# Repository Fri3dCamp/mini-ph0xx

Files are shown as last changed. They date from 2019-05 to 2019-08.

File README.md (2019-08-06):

# mini-ph0xx

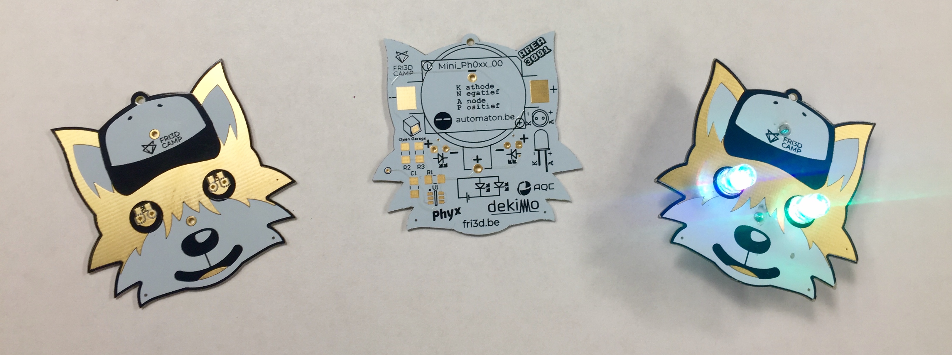
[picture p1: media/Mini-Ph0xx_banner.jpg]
Mini-Ph0xx banner


Design files voor de kleine badge die we op de [Maker Faire Gent 2019](http://makerfairegent.be) gebruikten om 1000 mensen te leren solderen.

De badge werd ontworpen door Wim Van Gool en Toon Vandeputte. Toon werkte een ontwerp uit in Illustrator en Wim integreerde dat met de PCB layout in Altium. Deze mini ph0xx badge is in alle opzichten de kleine broer van de [ph0xx badge](https://github.com/Fri3dCamp/badge) van Fri3d Camp 2018.

De badge heeft een through-hole design en twee SMD designs op 1 printplaat. Allen doen ze met een celbatterij twee oogjes oplichten. Met het tweede SMD circuit kan je het kopervlak rond de oortjes gebruiken als aan/uit touchpad.

Deze repository bevat 
* [De design files voor Altium](design)
* [De productiefiles van de rev.00 PCB zoals gebruikt op de Maker Faire](output/Mini-Ph0xx_00/PCB%20Production)
* [De productiefiles van de rev.01 PCB](output/Mini-Ph0xx_01/PCB%20Production)
* [Bill of Materials van de 3 circuits](output/Mini-Ph0xx_00/BOM)
* [Bill of Materials van de basic versie](output/Mini-Ph0xx_01/BOM)
* [Design in PDF formaat van rev.00](output/Mini-Ph0xx_00/Mini-Ph0xx_00.PDF)
* [Design in PDF formaat van rev.01](output/Mini-Ph0xx_01/Mini-Ph0xx_01.PDF)
* [Handleiding](Handleiding/Mini%20Ph0xx%20handleiding.pdf)
* [Iedereen kan solderen roll-up poster](Handleiding/Iedereen%20kan%20solderen.pdf)

Gebruik, copieer, verspreid!

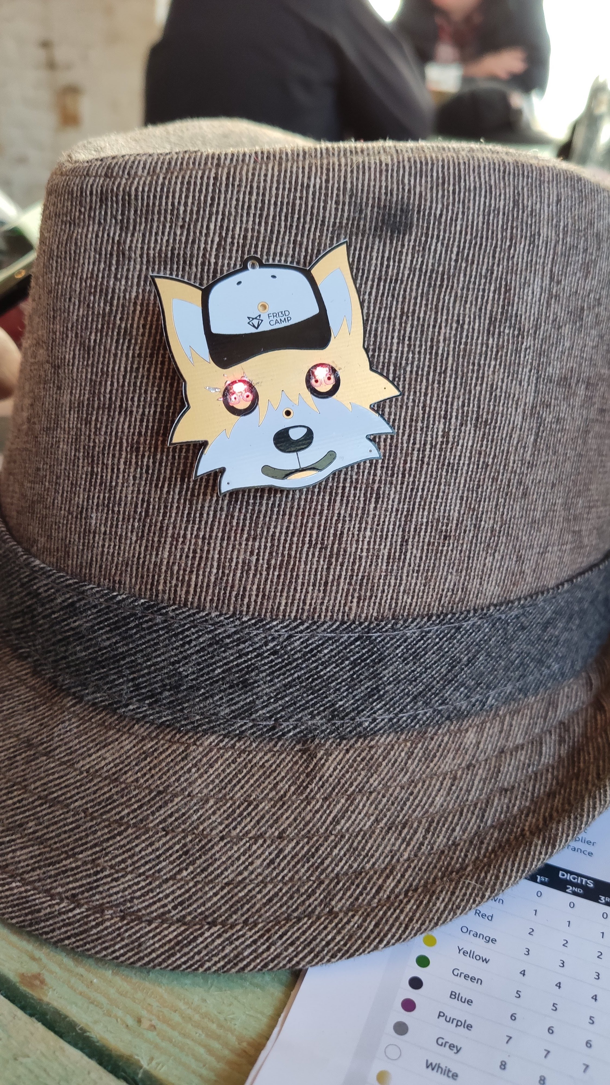
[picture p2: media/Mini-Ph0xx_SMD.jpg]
Mini-Ph0xx SMD


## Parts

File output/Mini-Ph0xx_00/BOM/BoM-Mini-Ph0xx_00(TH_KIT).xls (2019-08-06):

Bill of Materials |  |  | Mini Ph0xx
Project: |  | Mini-Ph0xx_00.PrjPcb
Revision: |  | 00
Variant: |  | TH_KIT
Creation Date: | 06/05/2019 | 22:11:42
Print Date: | 2019-05-06 | 22:12:12
Footprint | Comment | LibRef | Designator | Value | Description | Supplier 1 | Supplier Part Number 1 | Quantity
BAT_CR2032 | CR2032 Battery Holder | BAT 20mm Coin Cell Holder Generic | BAT1 | CR2032 |  | China |  | 1
LED_5MM_BL | Default 5mm Blue LED | LED Blue 5mm | D1, D2 |  |  |  |  | 2
 |  |  |  |  |  |  |  | 3
Approved |  | Notes

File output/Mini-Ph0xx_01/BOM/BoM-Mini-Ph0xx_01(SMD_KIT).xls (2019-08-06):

Bill of Materials |  |  | Mini Ph0xx
Project: |  | Fri3D_2019_SolderBadge_01.PrjPcb
Revision: |  | 01
Variant: |  | SMD_KIT
Creation Date: | 06/08/2019 | 21:38:42
Print Date: | 2019-08-06 | 21:40:05
Footprint | Comment | LibRef | Designator | Value | Description | Supplier 1 | Supplier Part Number 1 | Quantity
BAT_CR2032_KEY_1060 | CR2032 SMD Battery Holder | BAT # 20mm Coin Cell Holder Keystone 1060 | BAT2 | CR2032 |  | Digi-key | 36-1060-ND | 1
LED_0805_BL | Default 0805 Blue LED | LED # Blue 0805 | D3, D4 |  |  | Farnell | 2217980 | 2
 |  |  |  |  |  |  |  | 3
Approved |  | Notes

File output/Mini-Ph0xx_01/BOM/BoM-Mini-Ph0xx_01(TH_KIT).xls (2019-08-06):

Bill of Materials |  |  | Mini Ph0xx
Project: |  | Fri3D_2019_SolderBadge_01.PrjPcb
Revision: |  | 01
Variant: |  | TH_KIT
Creation Date: | 06/08/2019 | 21:38:14
Print Date: | 2019-08-06 | 21:39:32
Footprint | Comment | LibRef | Designator | Value | Description | Supplier 1 | Supplier Part Number 1 | Quantity
BAT_CR2032_China | CR2032 Battery Holder | BAT 20mm Coin Cell Holder Generic | BAT1 | CR2032 |  | China |  | 1
LED_5MM_BL | Default 5mm Blue LED | LED Blue 5mm | D1, D2 |  |  |  |  | 2
 |  |  |  |  |  |  |  | 3
Approved |  | Notes

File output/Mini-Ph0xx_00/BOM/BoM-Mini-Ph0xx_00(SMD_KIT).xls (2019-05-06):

Bill of Materials |  |  | Mini Ph0xx
Project: |  | Mini-Ph0xx_00.PrjPcb
Revision: |  | 00
Variant: |  | SMD_KIT
Creation Date: | 06/05/2019 | 22:11:46
Print Date: | 2019-05-06 | 22:12:49
Footprint | Comment | LibRef | Designator | Value | Description | Supplier 1 | Supplier Part Number 1 | Quantity
BAT_CR2032_KEY_1060 | CR2032 SMD Battery Holder | BAT # 20mm Coin Cell Holder Keystone 1060 | BAT2 | CR2032 |  | Digi-key | 36-1060-ND | 1
LED_0805_RD | Default 0805 Red LED | LED # Red 0805 | D3, D4 |  |  | Farnell | 2099236 | 2
R1206 | RESISTOR | RES # 0R 1206 | R1 | 0R |  | Farnell | 2497983 | 1
R1206 | RESISTOR | RES # 33R 1206 | R2, R3 | 33R |  |  |  | 2
 |  |  |  |  |  |  |  | 6
Approved |  | Notes

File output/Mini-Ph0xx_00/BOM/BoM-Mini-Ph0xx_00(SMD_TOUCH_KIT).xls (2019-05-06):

Bill of Materials |  |  | Mini Ph0xx
Project: |  | Mini-Ph0xx_00.PrjPcb
Revision: |  | 00
Variant: |  | SMD_TOUCH_KIT
Creation Date: | 06/05/2019 | 22:11:51
Print Date: | 2019-05-06 | 22:12:28
Footprint | Comment | LibRef | Designator | Value | Description | Supplier 1 | Supplier Part Number 1 | Quantity
BAT_CR2032_KEY_1060 | CR2032 SMD Battery Holder | BAT # 20mm Coin Cell Holder Keystone 1060 | BAT2 | CR2032 |  | Digi-key | 36-1060-ND | 1
C1206_N | CAP_CERAMIC | CAP # 22pF 50V 1206 | C1 | 22pF 50V | Capacitor Ceramic |  |  | 1
LED_0805_RD | Default 0805 Red LED | LED # Red 0805 | D3, D4 |  |  | Farnell | 2099236 | 2
R1206 | RESISTOR | RES # 33R 1206 | R2, R3 | 33R |  |  |  | 2
TP_0.8mm | TEST_PAD | TP # 0.8mm | TP1 | NO BOM |  |  |  | 1
SOT23-6 | Toggle dedicated touch IC | TOUCH # TTP223 | U1 | TTP223 |  | Aliexpress | TTP223 | 1
 |  |  |  |  |  |  |  | 8
Approved |  | Notes

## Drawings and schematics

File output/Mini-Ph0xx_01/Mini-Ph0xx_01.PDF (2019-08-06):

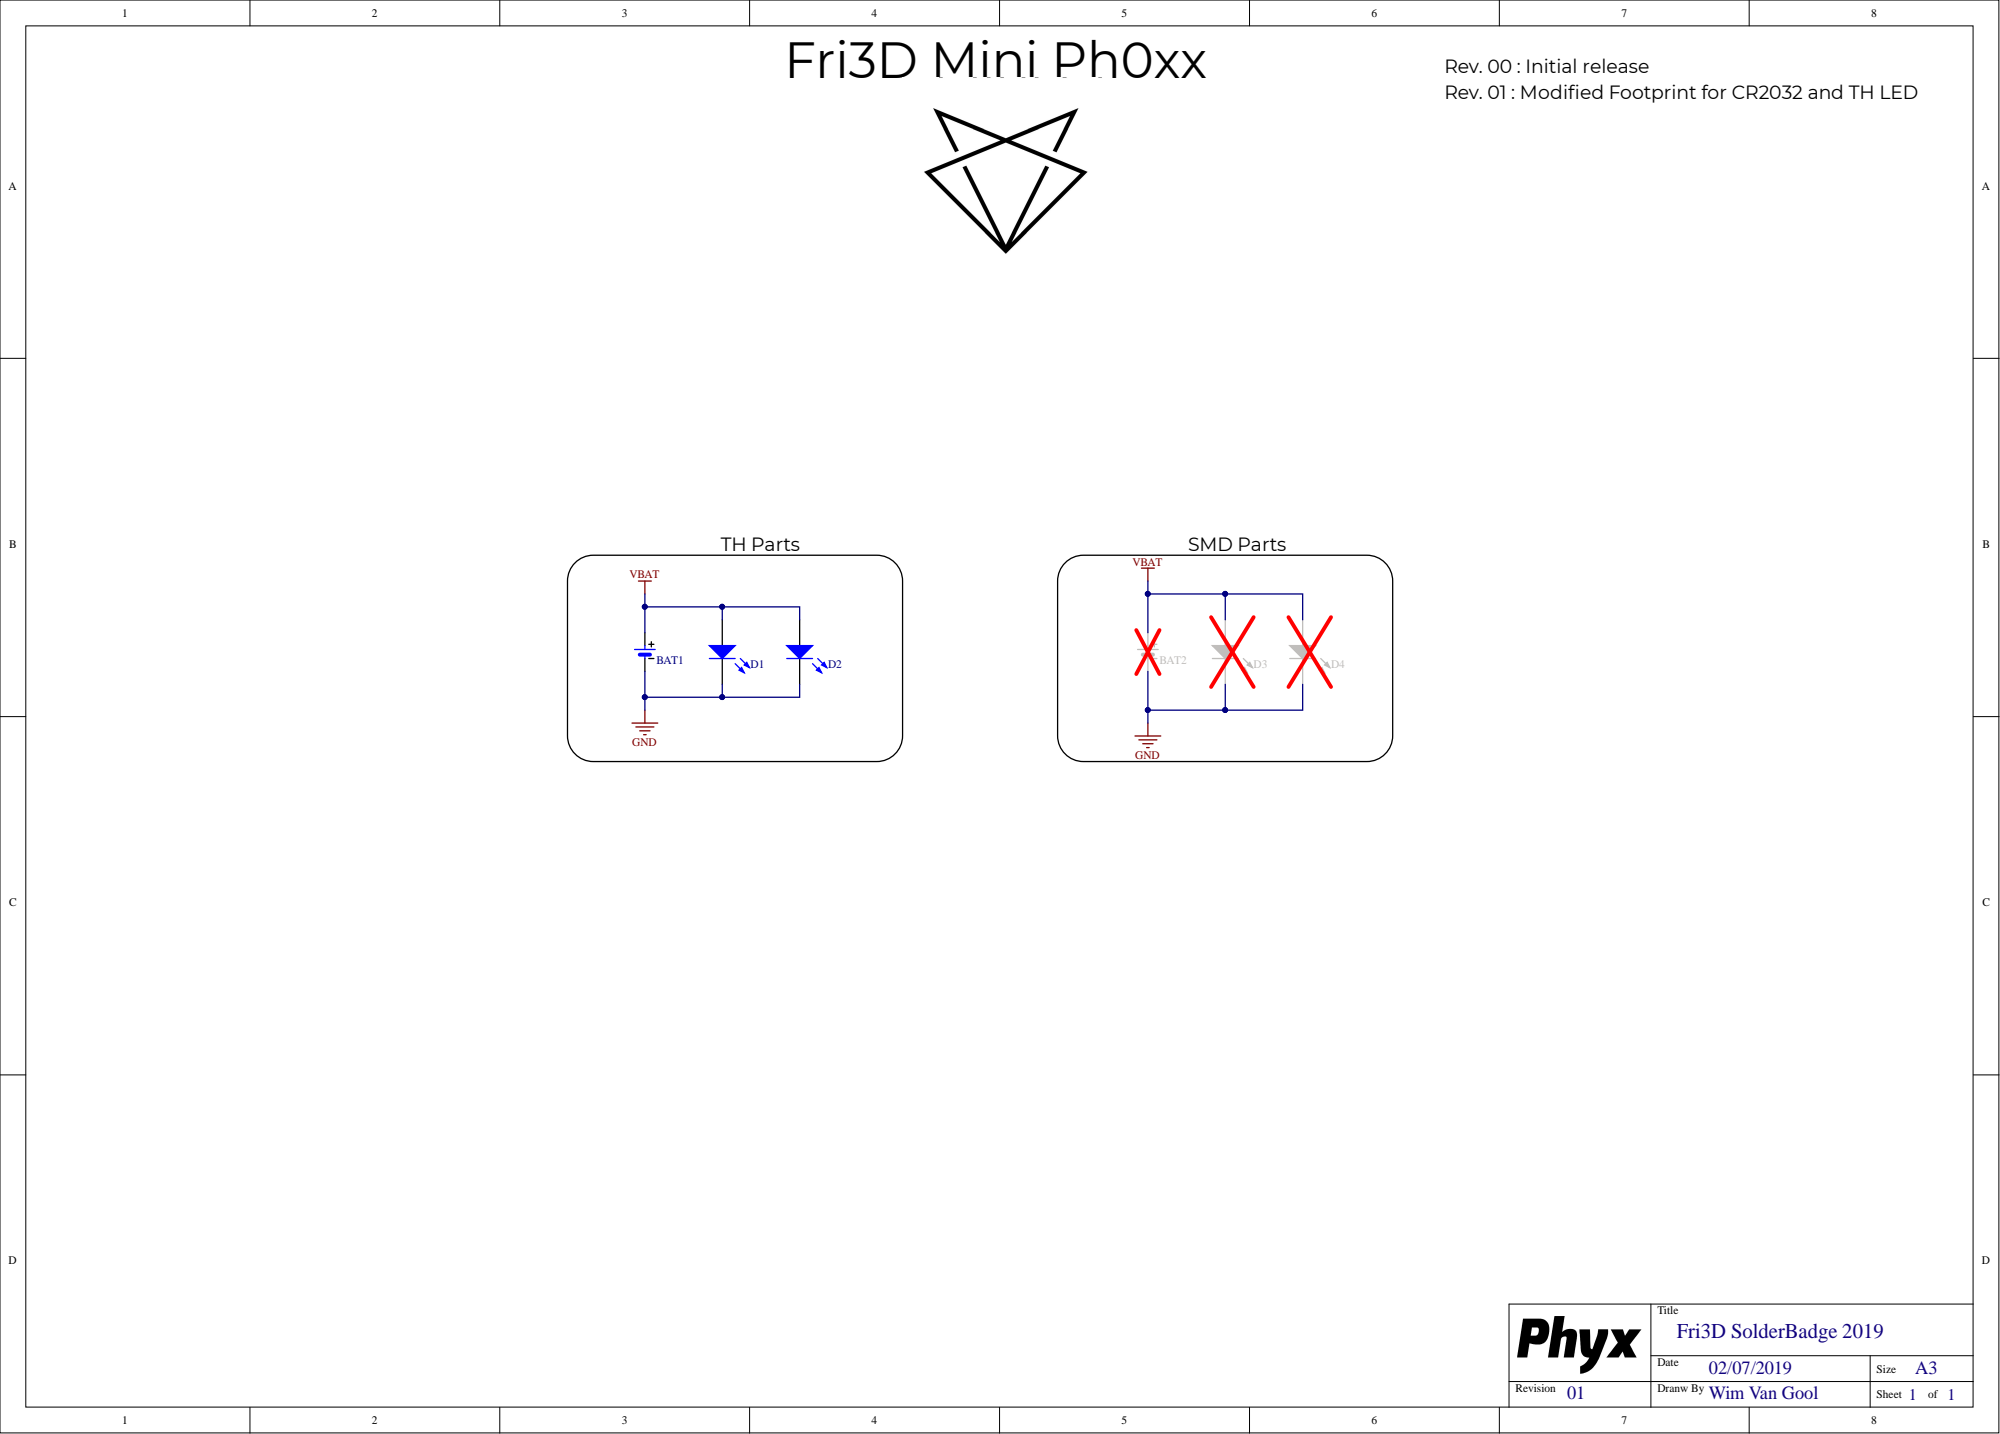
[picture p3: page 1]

for CR2032 and TH LED

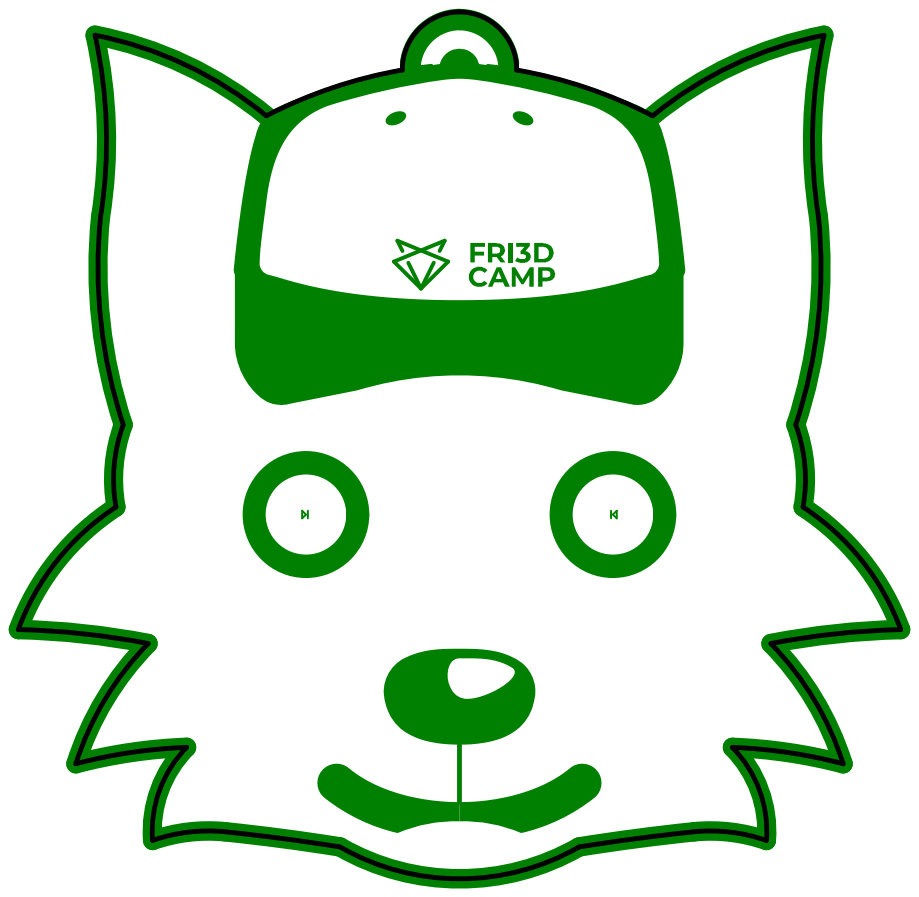
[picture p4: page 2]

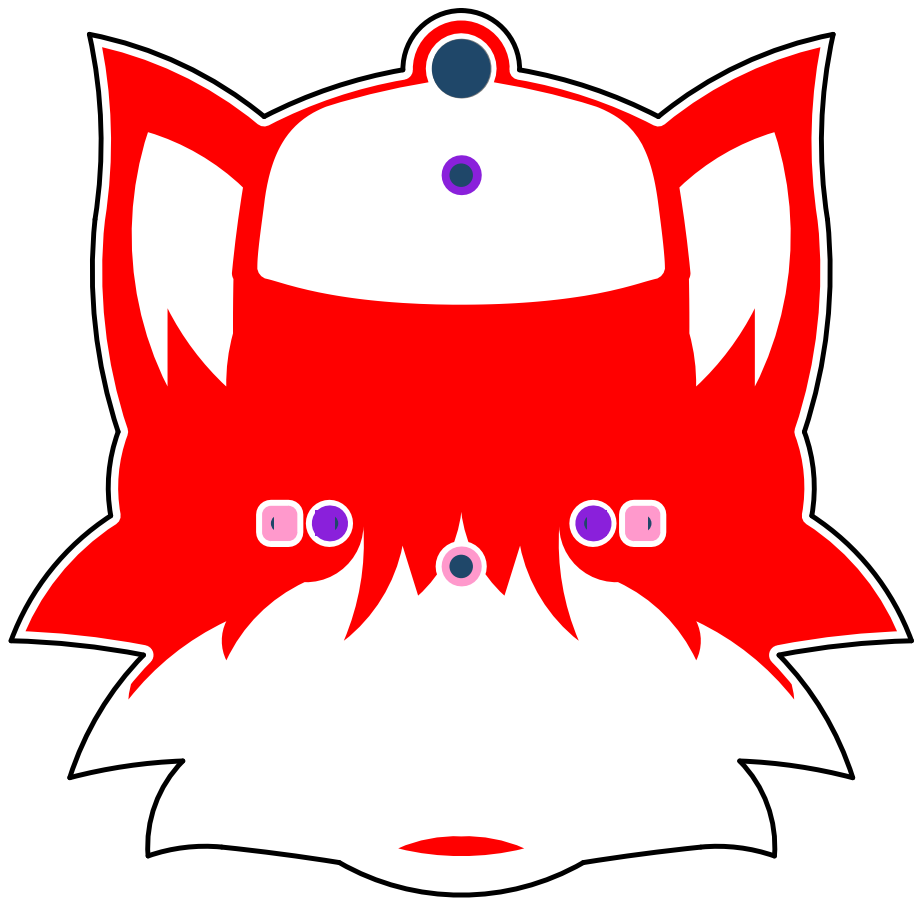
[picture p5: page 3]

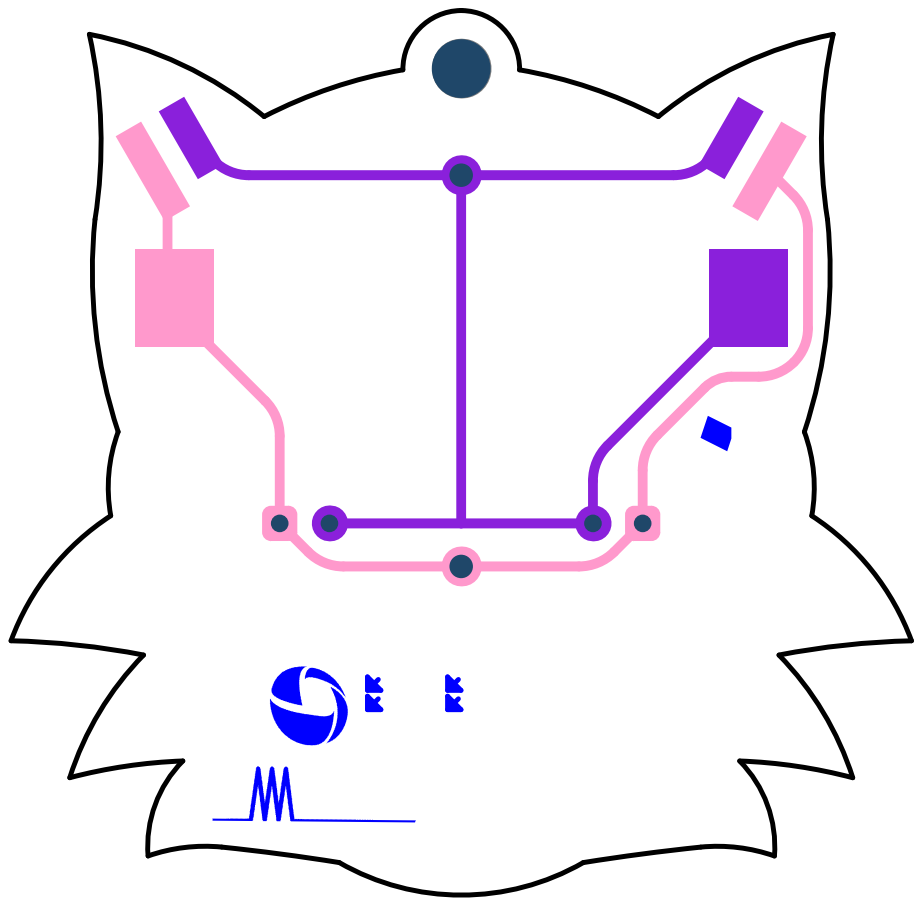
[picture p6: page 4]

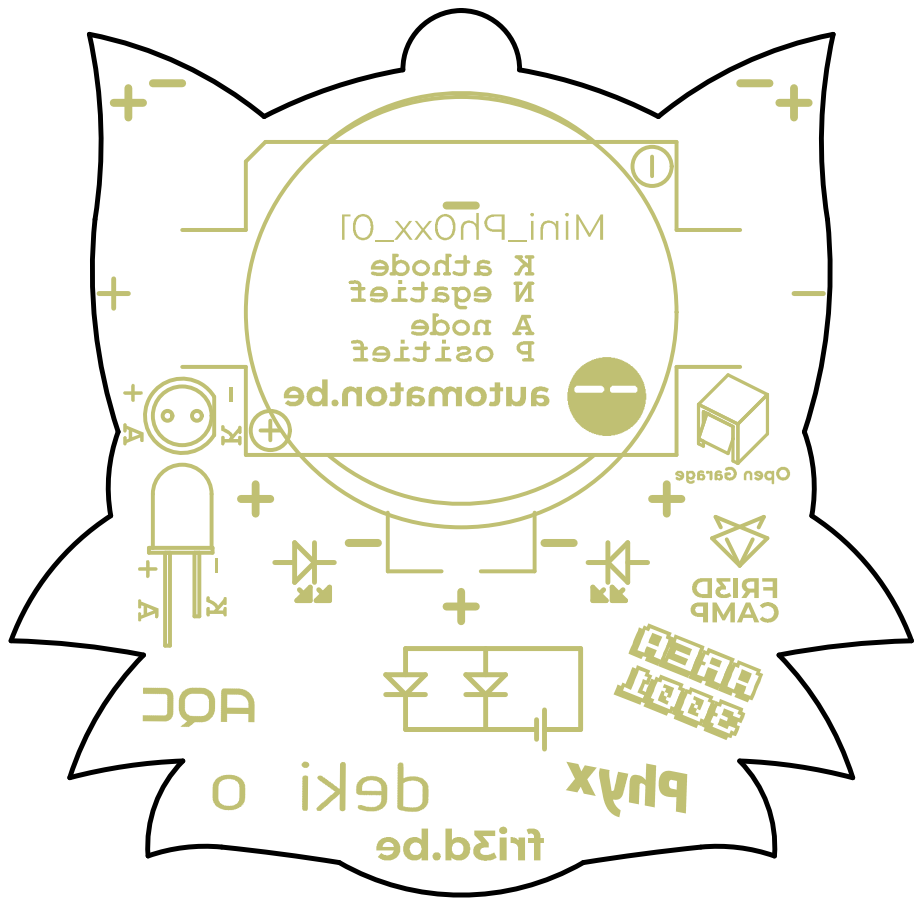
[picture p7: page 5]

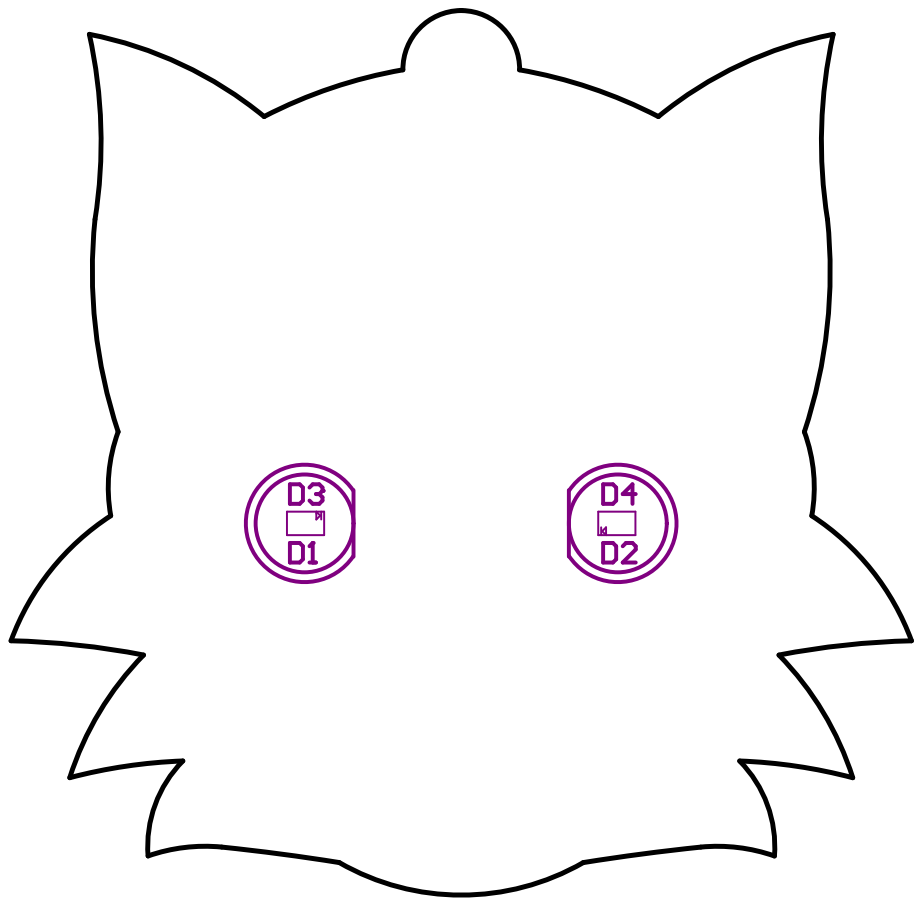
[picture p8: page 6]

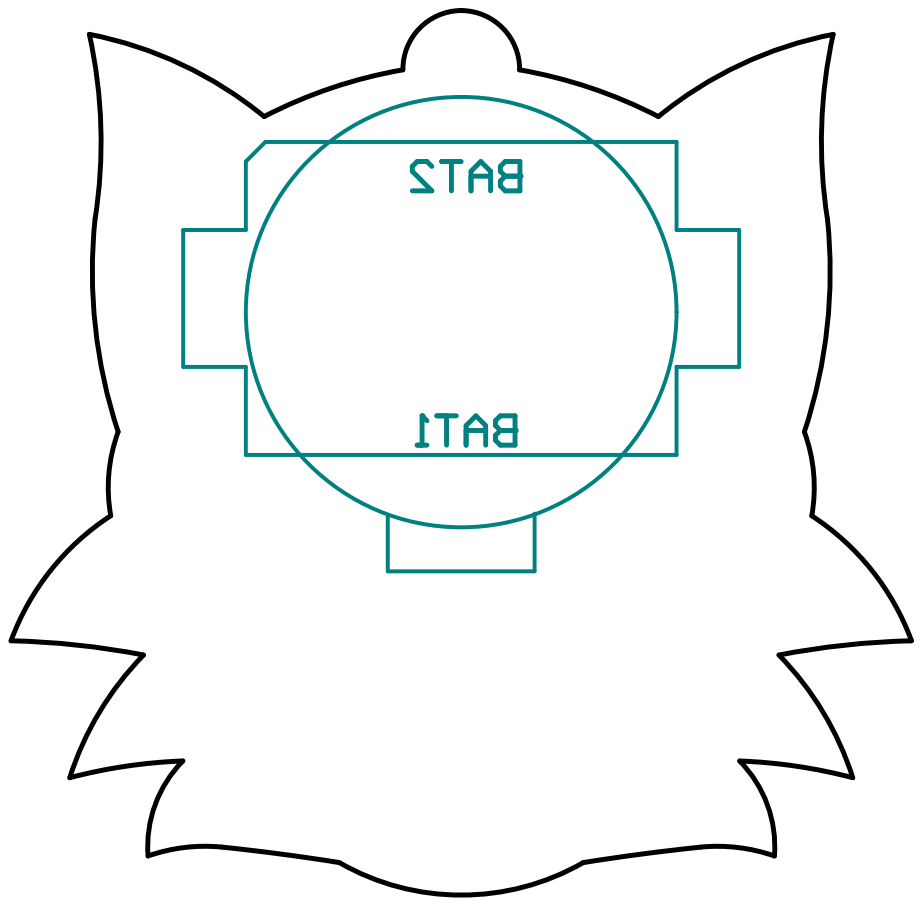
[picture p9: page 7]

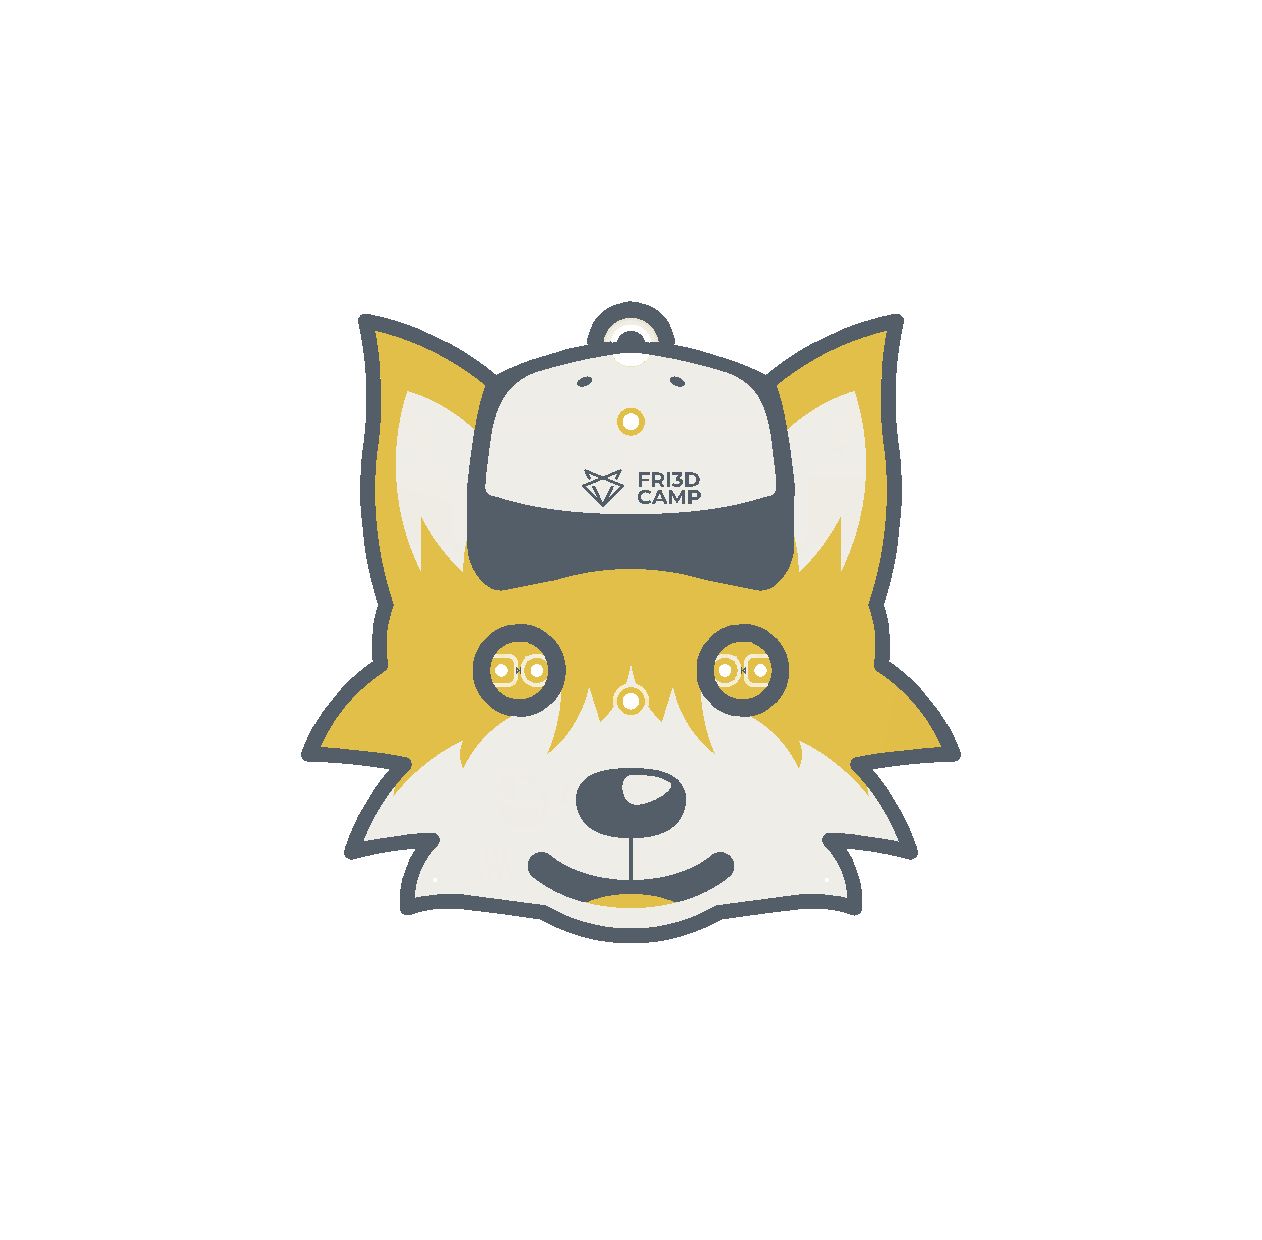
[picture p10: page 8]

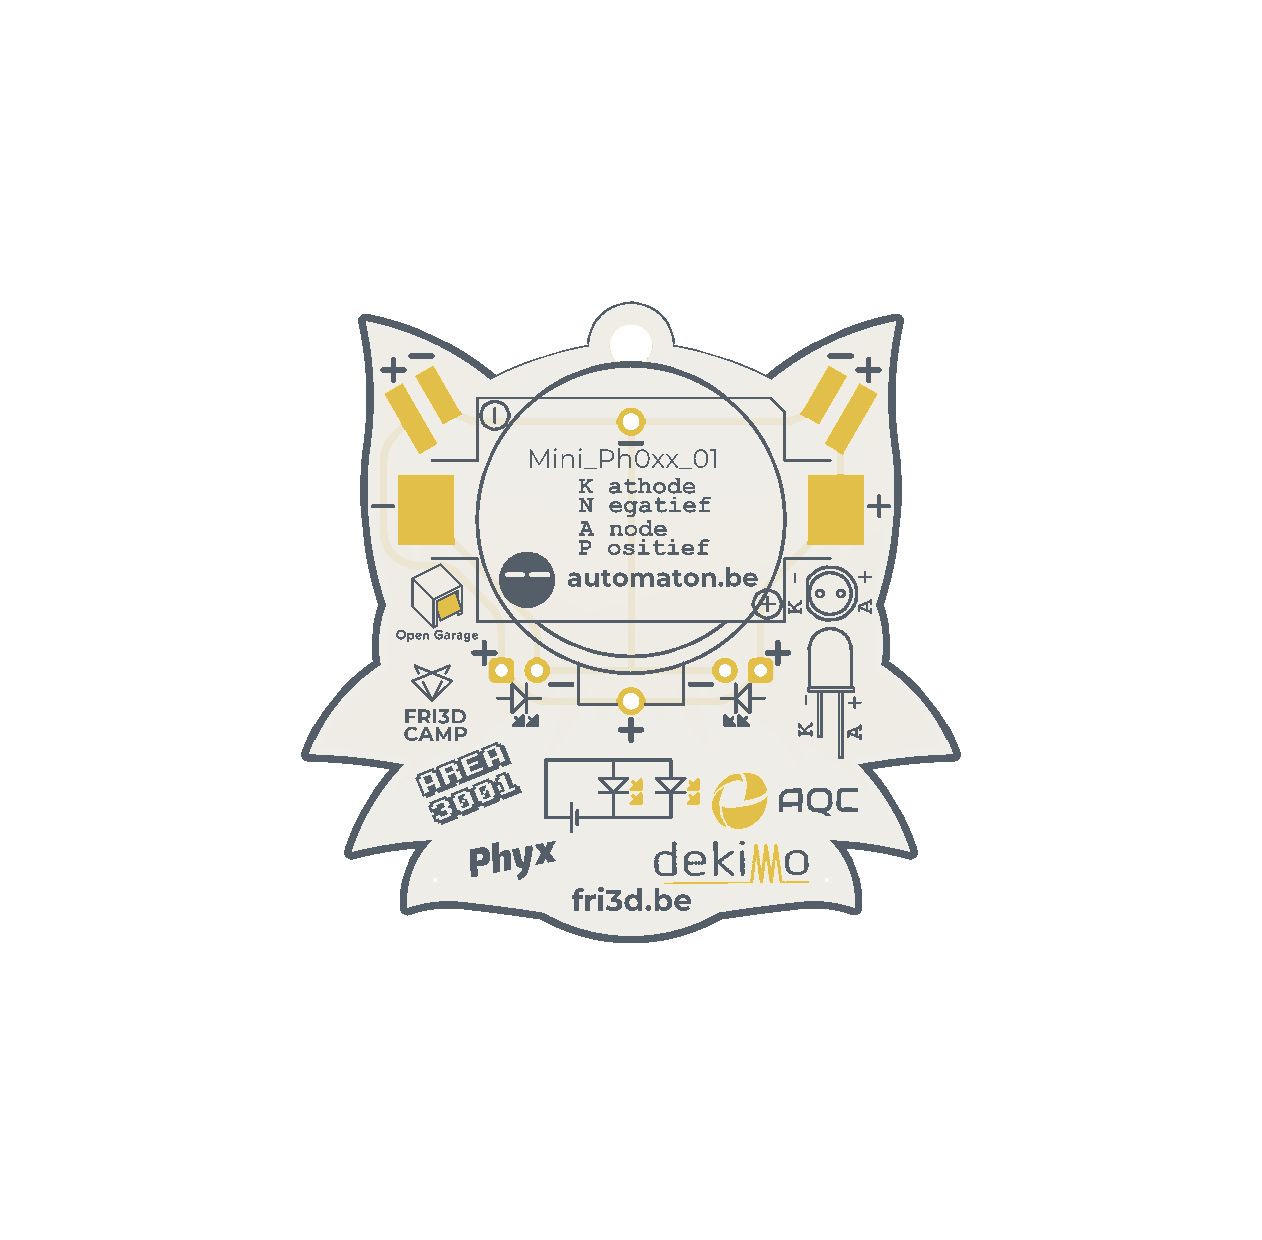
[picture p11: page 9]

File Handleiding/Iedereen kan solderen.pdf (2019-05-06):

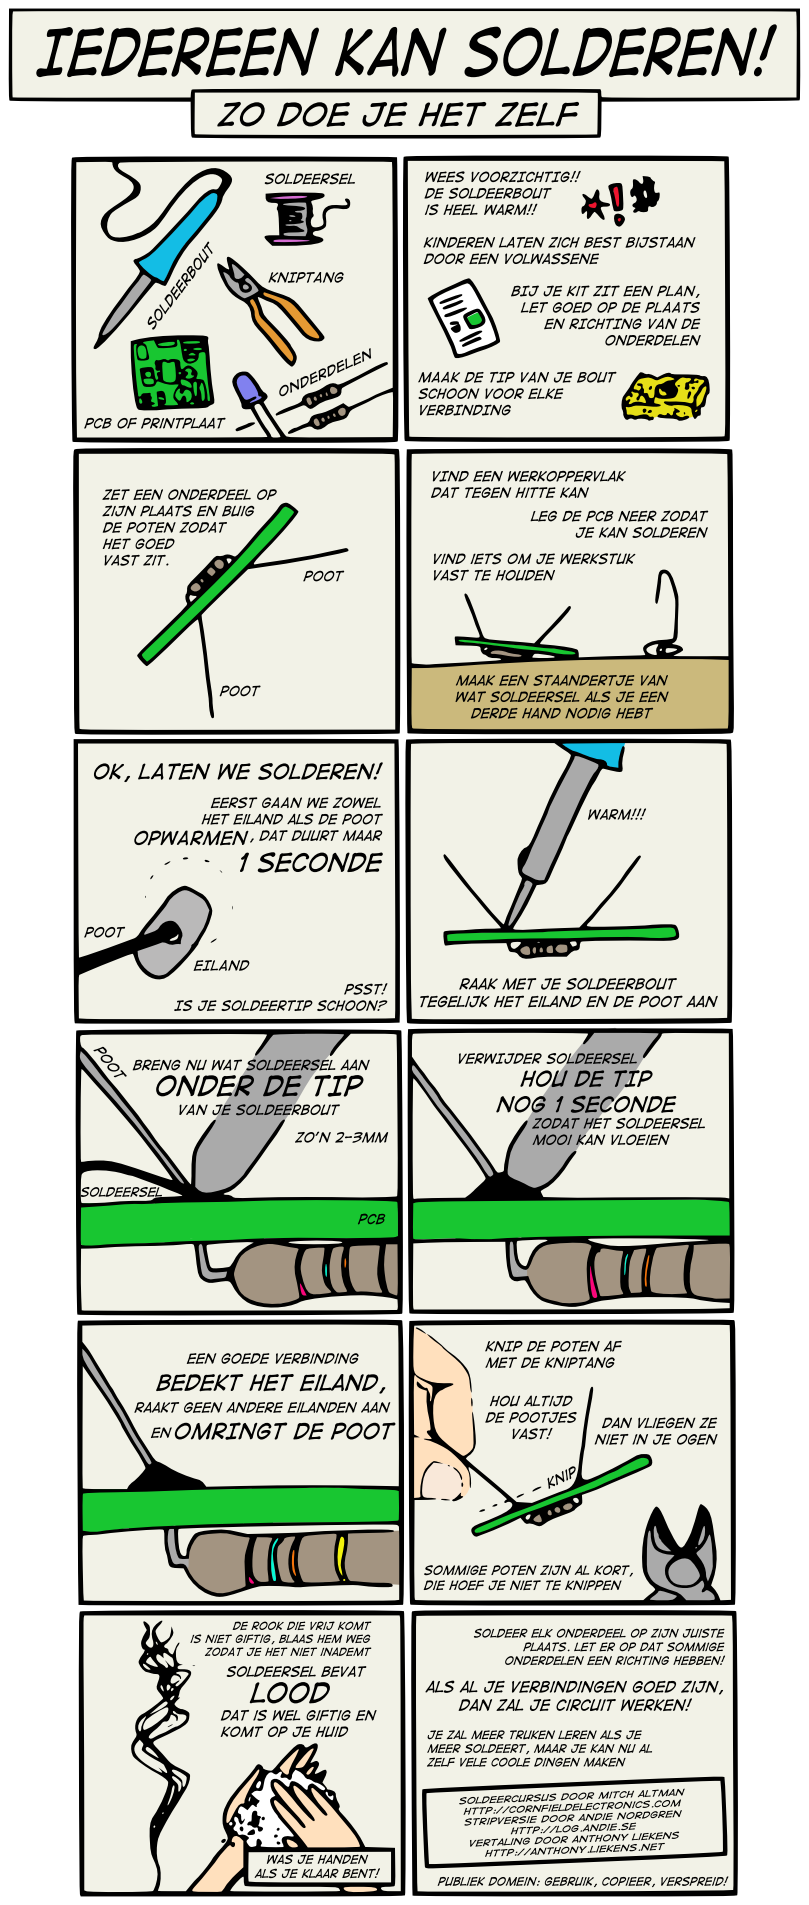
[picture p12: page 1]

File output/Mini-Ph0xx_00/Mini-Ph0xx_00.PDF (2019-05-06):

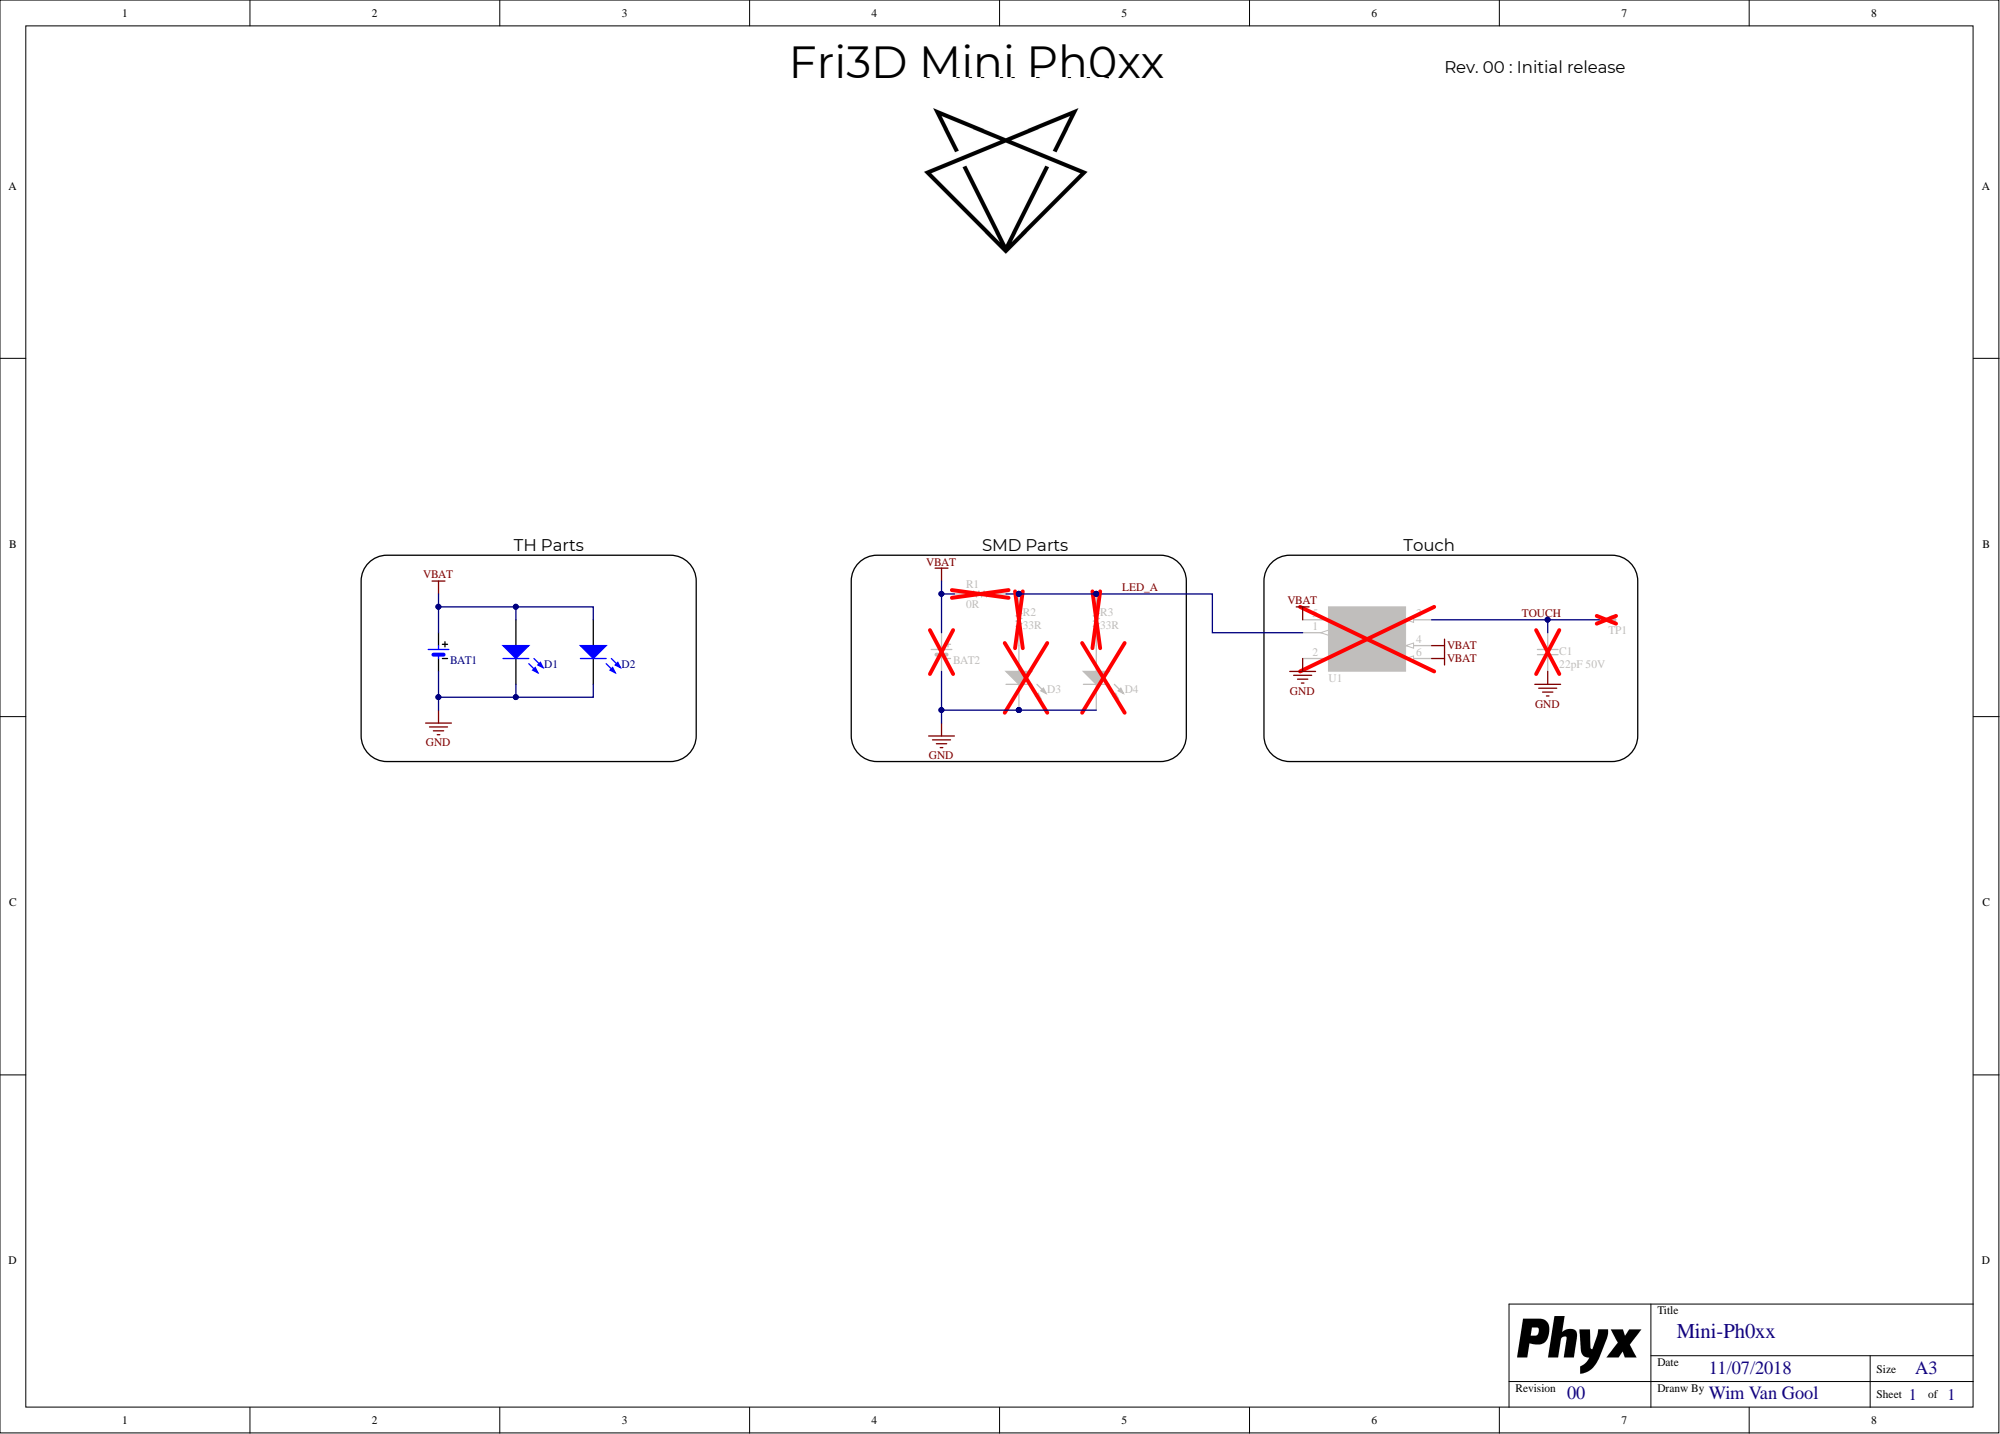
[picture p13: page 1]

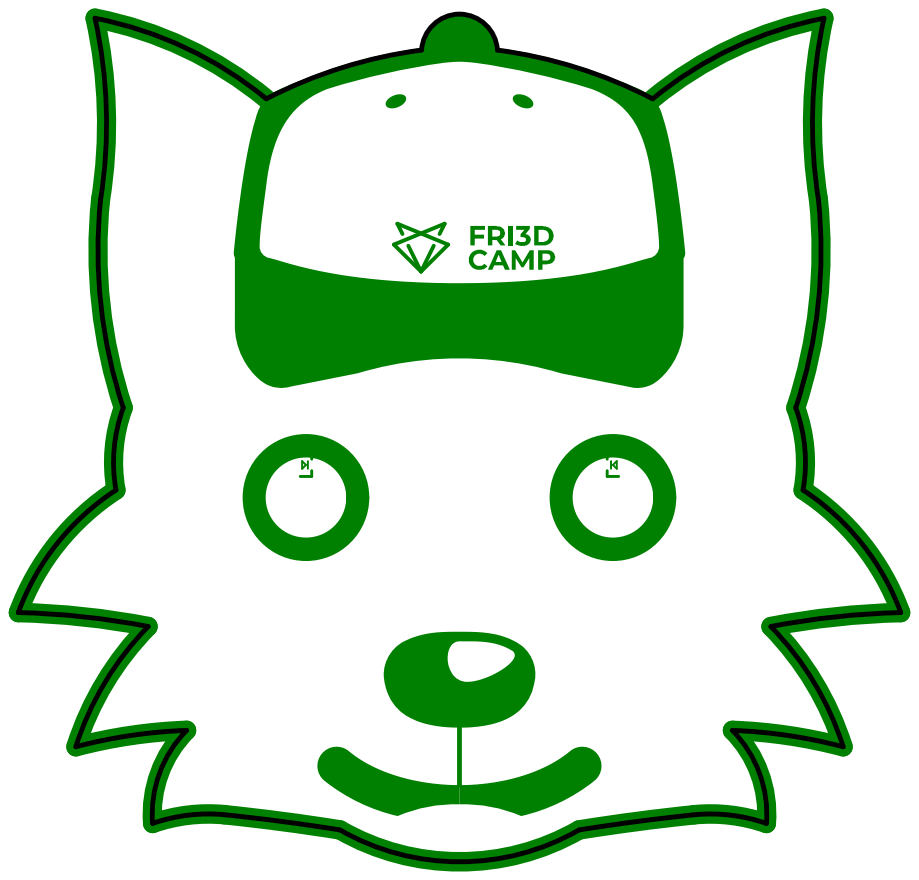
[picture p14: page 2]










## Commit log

2019-05-06 PDFs van handleiding en iedereen kan solderen rollup
2019-05-06 Design Files
    Design files and production data added
    [BoM-Mini-Ph0xx_00(SMD_KIT).xls, BoM-Mini-Ph0xx_00(SMD_TOUCH_KIT).xls, BoM-Mini-Ph0xx_00(TH_KIT).xls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]
2019-05-06 banner picture of PCBs
2019-05-06 move altium design files to their own dir
    [Mini-Ph0xx_00.PcbDoc, Mini-Ph0xx_00.PrjPcb, Mini-Ph0xx_00.SchDoc]
2019-08-06 Revision 01
    Added the design and production files for revision 01.
    [BoM-Mini-Ph0xx_00(SMD_KIT).xls, BoM-Mini-Ph0xx_00(SMD_TOUCH_KIT).xls, BoM-Mini-Ph0xx_00(TH_KIT).xls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]
2019-08-06 Project / SCH rev.01
    Added missing Project / schematic files for revision 01
    [Mini-Ph0xx_01.PrjPcb, Mini-Ph0xx_01.SchDoc]
